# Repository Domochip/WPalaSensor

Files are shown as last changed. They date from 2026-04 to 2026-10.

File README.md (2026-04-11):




# WPalaSensor

This project aims to replace the Palazzetti (Fumis) room temperature sensor by an electronic simulator.  
It allows you to push home automation temperature to the stove.  
You can then keep native modulation that reduce power automatically when desired temperature is reached.  

Fumis Controller

## Compatibility

It appears that Fumis Controller is used by those brands for their stoves : 

* Palazzetti (All)
* Jotul
* TurboFonte
* Godin
* Fonte Flamme
* Invicta

If you have this controller in your stove, it's likely to be compatible.  
Fumis Controller

## Build your adapter

All files are inside `schematic` subfolder and has been designed with KiCad (free and open source)

### Schematic

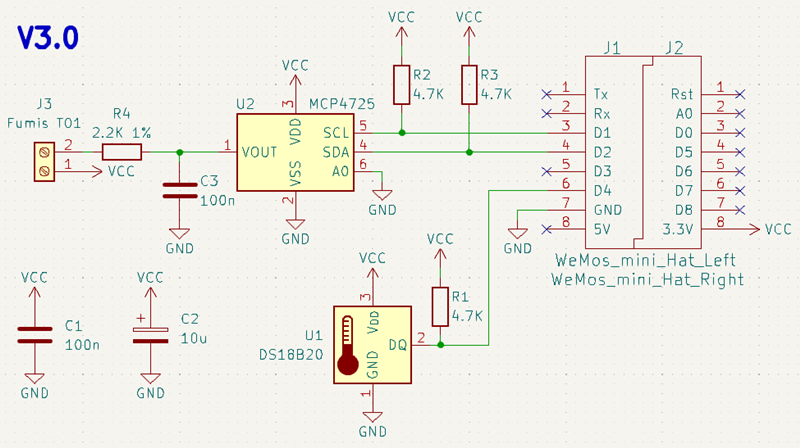
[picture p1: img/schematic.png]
WPalaSensor schematic


### PCB

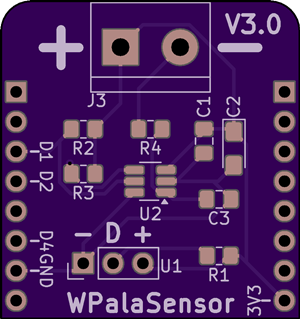
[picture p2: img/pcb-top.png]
WPalaSensor PCB
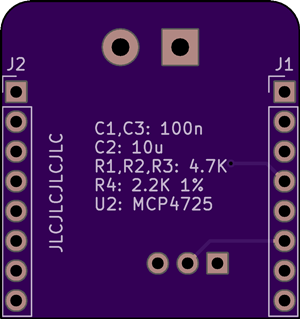
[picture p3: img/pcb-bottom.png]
WPalaSensor PCB2


*We produced a small batch of this adapter for test/debugging and our personal use.
If you are interested, please PM.*

### Print your box

Box project (Fusion 360 & STL) can be found into `box` folder

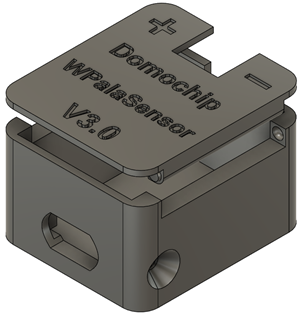
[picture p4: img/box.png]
WPalaSensor box


### Code/Compile/Flash

Source code can be compiled using VisualStudioCode/Platformio and flashed onto a D1 Mini  
Or  
Download latest release in Release section

### Connect

⚠️To connect WPalaSensor to your stove, you need to be very carefull about the polarity⚠️.  
Here is the polarity of two possible temperature sensors on Fumis motherboard:  
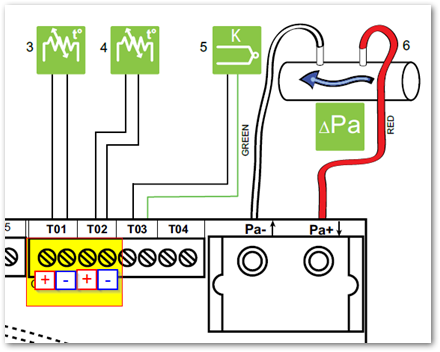
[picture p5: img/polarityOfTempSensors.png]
WPalaSensor polarity


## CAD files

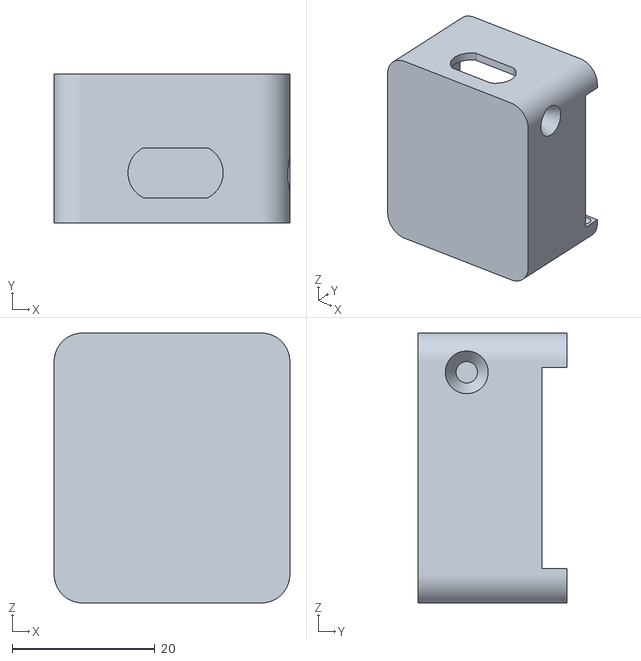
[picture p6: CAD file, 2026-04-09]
box/WPalaSensor Box.stl
33.0 x 20.8 x 37.8

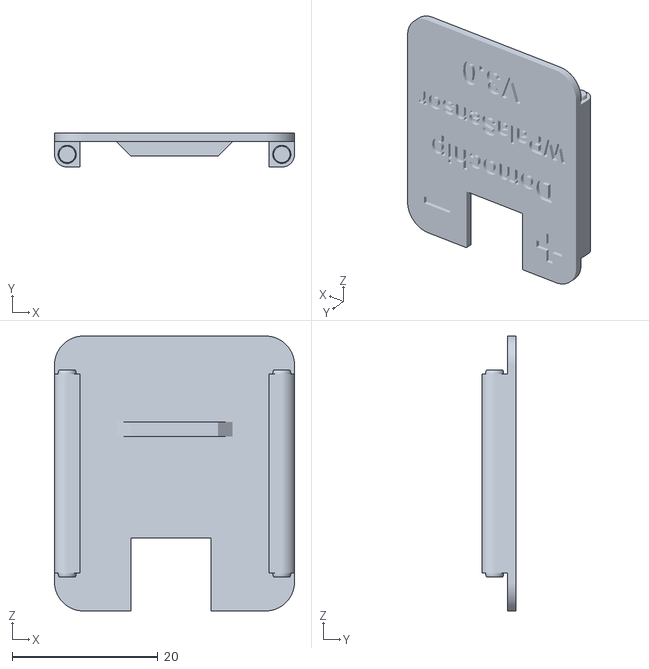
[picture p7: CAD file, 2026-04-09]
box/WPalaSensor Lid.stl
33.0 x 4.70 x 37.8

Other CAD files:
box/WPalaSensor v6.f3d

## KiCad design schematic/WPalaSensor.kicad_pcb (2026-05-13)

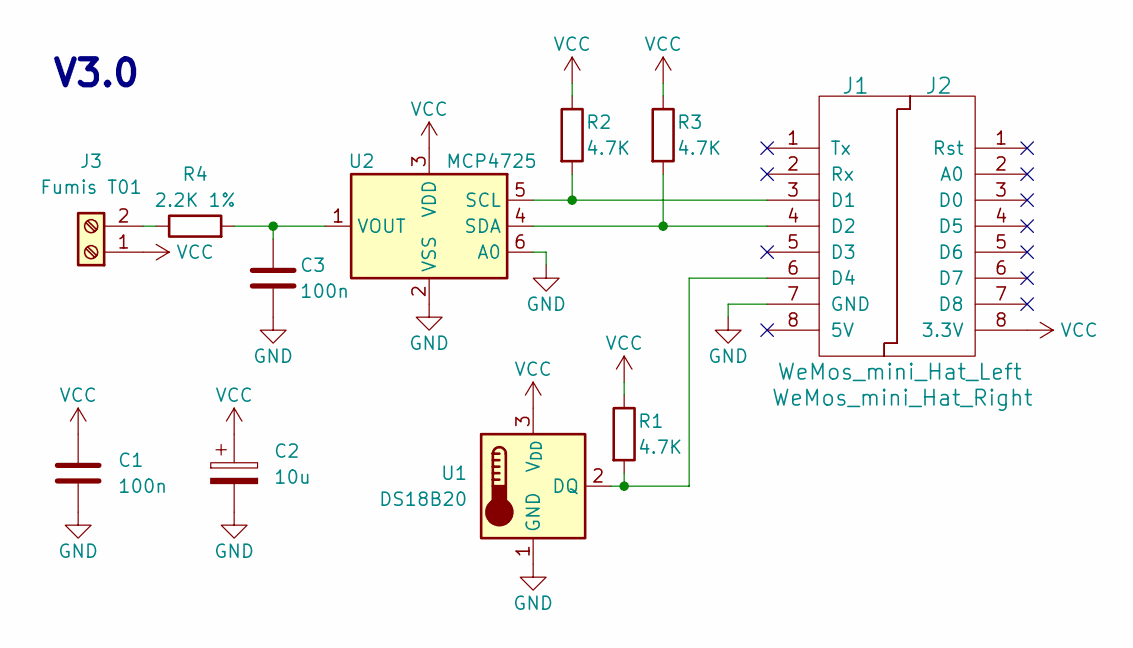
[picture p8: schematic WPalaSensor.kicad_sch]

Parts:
C1, C3: 100n; C_0805_2012Metric_Pad1.18x1.45mm_HandSolder; LCSC C49678
C2: 10u; CP_EIA-3216-18_Kemet-A_Pad1.58x1.35mm_HandSolder; LCSC C7171
J1: WeMos_mini_Hat_Left; WeMos_D1_mini_Hat_Left; LCSC C7509515
J2: WeMos_mini_Hat_Right; WeMos_D1_mini_Hat_Right; LCSC C7509515
J3: Fumis T01; TerminalBlock_bornier-2_P5.08mm; LCSC C474881
R1, R2, R3: 4.7K; R_0805_2012Metric_Pad1.20x1.40mm_HandSolder; LCSC C17673
R4: 2.2K 1%; R_0805_2012Metric_Pad1.20x1.40mm_HandSolder; LCSC C17520
U1: DS18B20; PinHeader_1x03_P2.54mm_Vertical
U2: MCP4725; SOT-23-6_Handsoldering; LCSC C144198

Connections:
GND: C1.2, C2.2, C3.2, J1.7 (GND), U1.1 (GND), U2.2 (VSS), U2.6 (A0)
unnamed: J1.3 (D1), R2.2, U2.5 (SCL)
unnamed: J1.4 (D2), R3.2, U2.4 (SDA)
unnamed: J1.6 (D4), R1.2, U1.2 (DQ)
unnamed: J3.2, R4.1
unnamed: C3.1, R4.2, U2.1 (VOUT)
VCC: C1.1, C2.1, J2.8 (3.3V), J3.1, R1.1, R2.1, R3.1, U1.3 (V_{DD}), U2.3 (VDD)

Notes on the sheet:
V3.0

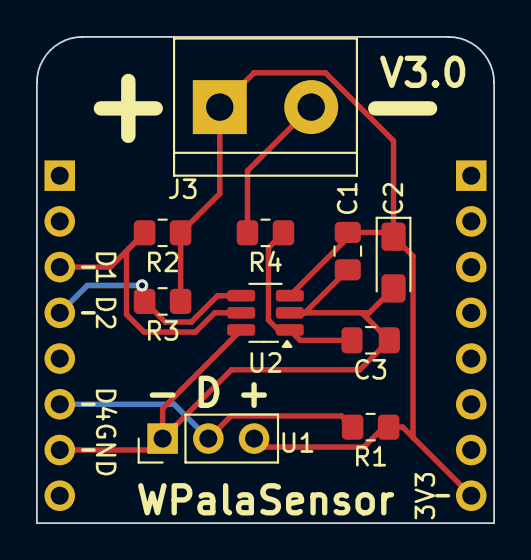
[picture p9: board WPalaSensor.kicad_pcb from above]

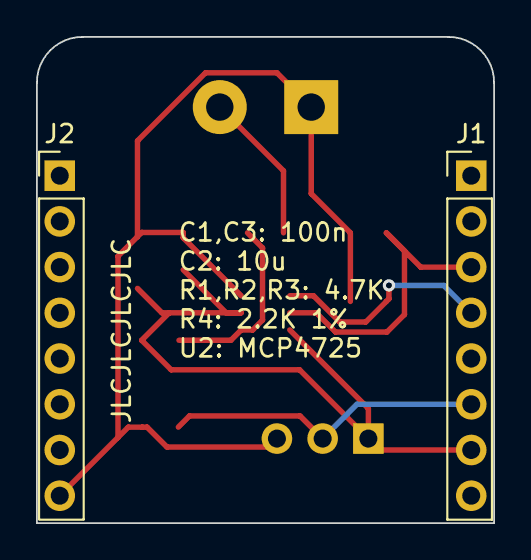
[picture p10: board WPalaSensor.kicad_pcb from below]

Board: 2 copper layers, 25.4 x 27.0 mm, 12 parts (2 on the bottom side), 7 nets.

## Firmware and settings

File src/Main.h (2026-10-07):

#ifndef Main_h
#define Main_h

#include <Arduino.h>

// Helper macros to convert a define to a string
#define STRINGIFY(x) #x
#define TOSTRING(x) STRINGIFY(x)

// ----- Should be modified for your application -----
#define CUSTOM_APP_MANUFACTURER "Domochip" // also used as Github user for OTA
#define CUSTOM_APP_MODEL "WPalaSensor"     // also used as Github repository for OTA
#define CUSTOM_APP_CLASS WPalaSensor
#define VERSION_NUMBER "4.3.7"

#define CUSTOM_APP_HEADER TOSTRING(CUSTOM_APP_CLASS.h) // calculated header file "{CUSTOM_APP_CLASS}.h"
#define DEFAULT_AP_SSID CUSTOM_APP_MODEL               // Default Access Point SSID "{CUSTOM_APP_MODEL}"
#define DEFAULT_AP_PSK "password"                      // Default Access Point Password

// Control SSEServer code (To be used by Application if Server-sent events are needed)
#define SSE_SERVER_ENABLED 0
#define SSE_SERVER_MAX_CLIENTS 2
#define SSE_SERVER_KEEPALIVE 0

// Pin for 1Wire DS18B20 bus
#ifdef ESP8266
#define ONEWIRE_BUS_PIN D4
#else
#define ONEWIRE_BUS_PIN 16
#endif

// Enable developper mode
#define DEVELOPPER_MODE 0

// Log Serial Object
#define LOG_SERIAL Serial
// Choose Log Serial Speed
#define LOG_SERIAL_SPEED 115200

// Log Serial Macros
#ifdef LOG_SERIAL
#define LOG_SERIAL_PRINT(...) LOG_SERIAL.print(__VA_ARGS__)
#define LOG_SERIAL_PRINTLN(...) LOG_SERIAL.println(__VA_ARGS__)
#define LOG_SERIAL_PRINTF(...) LOG_SERIAL.printf(__VA_ARGS__)
#define LOG_SERIAL_PRINTF_P(...) LOG_SERIAL.printf_P(__VA_ARGS__)
#else
#define LOG_SERIAL_PRINT(...)
#define LOG_SERIAL_PRINTLN(...)
#define LOG_SERIAL_PRINTF(...)
#define LOG_SERIAL_PRINTF_P(...)
#endif

// Choose Pin used to boot in Rescue Mode
// #define RESCUE_BTN_PIN 16

// Status LED
// #define STATUS_LED_SETUP pinMode(XX, OUTPUT);pinMode(XX, OUTPUT);
// #define STATUS_LED_OFF digitalWrite(XX, HIGH);digitalWrite(XX, HIGH);
// #define STATUS_LED_ERROR digitalWrite(XX, HIGH);digitalWrite(XX, HIGH);
// #define STATUS_LED_WARNING digitalWrite(XX, HIGH);digitalWrite(XX, HIGH);
// #define STATUS_LED_GOOD digitalWrite(XX, HIGH);digitalWrite(XX, HIGH);

// construct Version text
#if DEVELOPPER_MODE
#define _DEV_SUFFIX "-DEV"
#else
#define _DEV_SUFFIX ""
#endif

#ifdef DEBUG
#define _DEBUG_SUFFIX "-DEBUG"
#else
#define _DEBUG_SUFFIX ""
#endif

#define VERSION VERSION_NUMBER _DEV_SUFFIX _DEBUG_SUFFIX

#endif

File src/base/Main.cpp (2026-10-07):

#ifdef ESP8266
#include <ESP8266WiFi.h>
#include <ESP8266WebServer.h>
using WebServer = ESP8266WebServer;
#else
#include <WiFi.h>
#include <WebServer.h>
#endif
#include <EEPROM.h>
#include <LittleFS.h>
#include <FS.h>

#include "Version.h"
#include "../Main.h"
#include "SystemState.h"
#include "Application.h"
#include "Core.h"
#include "WifiMan.h"

// include Custom Application header file
#include CUSTOM_APP_HEADER

// WebServer
WebServer server(80);

// Core App
Core core;

// WifiMan App
WifiMan wifiMan;

// Custom App
CUSTOM_APP_CLASS custom;

//-----------------------------------------------------------------------
// Setup function
//-----------------------------------------------------------------------
void setup()
{
#ifdef LOG_SERIAL
  LOG_SERIAL.begin(LOG_SERIAL_SPEED);
  LOG_SERIAL_PRINTLN();
  LOG_SERIAL_PRINTLN();
  LOG_SERIAL.flush();
#endif

#ifdef STATUS_LED_SETUP
  STATUS_LED_SETUP
#endif
#ifdef STATUS_LED_ERROR
  STATUS_LED_ERROR
#endif

  LOG_SERIAL_PRINTLN(F(CUSTOM_APP_MANUFACTURER " " CUSTOM_APP_MODEL " " VERSION));
  LOG_SERIAL_PRINTLN(F("---Booting---"));

#ifndef RESCUE_BUTTON_WAIT
#define RESCUE_BUTTON_WAIT 3
#endif

  bool skipExistingConfig = false;

  // look into EEPROM for Rescue mode flag
  EEPROM.begin(4);
  skipExistingConfig = EEPROM.read(0) != 0;
  if (skipExistingConfig)
    EEPROM.write(0, 0);
  EEPROM.end();

#ifdef RESCUE_BTN_PIN
  // if config already skipped, don't wait for rescue button
  if (!skipExistingConfig)
  {
    LOG_SERIAL_PRINTF_P(PSTR("Wait Rescue button for %d seconds\n"), RESCUE_BUTTON_WAIT);

    pinMode(RESCUE_BTN_PIN, (RESCUE_BTN_PIN != 16) ? INPUT_PULLUP : INPUT);
    for (int i = 0; i < 100 && skipExistingConfig == false; i++)
    {
      if (digitalRead(RESCUE_BTN_PIN) == LOW)
        skipExistingConfig = true;
      delay(RESCUE_BUTTON_WAIT * 10);
    }
  }
#endif

  if (skipExistingConfig)
  {
    LOG_SERIAL_PRINTLN(F("-> RESCUE MODE : Stored configuration won't be loaded."));
  }
  
#ifdef ESP8266
  if (!LittleFS.begin())
#else
  if (!LittleFS.begin(true))
#endif
  {
    LOG_SERIAL_PRINTLN(F("/!\\   File System Mount Failed   /!\\"));
    LOG_SERIAL_PRINTLN(F("/!\\ Configuration can't be saved /!\\"));
  }

#ifdef ESP8266
  // Init CrashSaver
  CrashSaver::init(LittleFS);
#endif

  // Init Core
  core.init(skipExistingConfig);

  // Init WiFi
  wifiMan.init(skipExistingConfig);

  // Init Custom Application
  custom.init(skipExistingConfig);

  LOG_SERIAL_PRINT(F("Start WebServer : "));

  core.initWebServer(server);
  wifiMan.initWebServer(server);
  custom.initWebServer(server);

  server.begin();

  LOG_SERIAL_PRINTLN(F("OK"));
  LOG_SERIAL_PRINTLN(F("---End of setup()---"));
}

//-----------------------------------------------------------------------
// Main Loop function
//-----------------------------------------------------------------------
void loop(void)
{

  // Handle WebServer
  server.handleClient();

  if (!SystemState::pauseCustomApp && !SystemState::shouldReboot)
    custom.run();

  wifiMan.run();

  // required to maintain WiFi and send tcp packets (particularly for mesh wifi)
#ifdef ESP8266
  delay(10);
#endif

  if (SystemState::shouldReboot)
  {
#ifdef LOG_SERIAL
    LOG_SERIAL_PRINTLN(F("Rebooting..."));
    delay(100);
    LOG_SERIAL.end();
#endif
    ESP.restart();
  }
}

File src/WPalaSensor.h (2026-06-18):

#ifndef WPalaSensor_h
#define WPalaSensor_h

#include "Main.h"
#include "base/WifiMan.h"
#include "base/MQTTMan.h"
#include "base/Application.h"

#ifdef ESP8266
#include <ESP8266HTTPClient.h>
#else
#include <HTTPClient.h>
#endif
#include <SPI.h>
#include <math.h>
#include <Ticker.h>
#include "SingleDS18B20.h"
#include <MCP4725.h>

class WPalaSensor : public Application
{
private:
  // -------------------- HomeAutomation Classes --------------------

  enum class HaHttpType : uint8_t
  {
    Jeedom = 0,
    Fibaro = 1,
    HomeAssistant = 2
  };

  enum class HaProtocol : uint8_t
  {
    Disabled = 0,
    Http = 1,
    Mqtt = 2
  };

  enum class CBoxProtocol : uint8_t
  {
    Disabled = 0,
    Http = 1,
    Mqtt = 2
  };

  struct HTTP
  {
    HaHttpType type;
    char hostname[64 + 1];
    bool tls;
    int temperatureId;
    char secret[183 + 1]; // store Home Assistant long lived access token or Jeedom API key or Fibaro password

    struct
    {
      char username[64 + 1];
    } fibaro;

    struct
    {
      char entityId[64 + 1];
    } homeassistant;

    uint32_t cboxIp;
  };

  struct MQTT
  {
    char hostname[64 + 1];
    uint16_t port;
    char username[32 + 1];
    char password[64 + 1];
    char baseTopic[64 + 1];
    bool hassDiscoveryEnabled;
    char hassDiscoveryPrefix[32 + 1];

    char temperatureTopic[64 + 1];

    char cboxT1Topic[32 + 1];
  };

  struct HomeAutomation
  {
    HaProtocol protocol;
    uint16_t temperatureTimeout;
    CBoxProtocol cboxProtocol;
    uint16_t cboxTemperatureTimeout;

    HTTP http;
    MQTT mqtt;
  };

  // --------------------

  uint8_t _refreshPeriod;
  // Steinhart-Hart coefficient A
  double _shA;
  // Steinhart-Hart coefficient B
  double _shB;
  // Steinhart-Hart coefficient C
  double _shC;
  HomeAutomation _ha;

  // Run variables

  SingleDS18B20 _ds18b20;
  MCP4725 _dac;

  bool _needRefresh = false;
  Ticker _refreshTicker;
  uint8_t _skipTick = 0;
  bool _needPublishHassDiscovery = false;
  bool _needPublishUpdate = false;
  Ticker _publishUpdateTicker;

  // Used in refresh method for logic and calculation

  // to avoid delta calculation on first call (then 20° is applied at first call and then delta is calculated at least during 2nd call)
  bool _firstRefreshTick = true;

  float _haTemperature = 20.0;
  unsigned long _haTemperatureMillis = 0;
  int _haRequestResult = 0;
  float _owTemperature = 0.0;
  bool _haTemperatureUsed = false;
  float _lastTemperatureUsed = 20.0;

  float _stoveTemperature = 20.0;
  unsigned long _stoveTemperatureMillis = 0;
  int _stoveRequestResult = 0;

  float _stoveDelta = 0.0;
  float _pushedTemperature = 20.0;

  WiFiClient _wifiClient; // used by _mqttMan
  MQTTMan _mqttMan;

  void setDac(float temperature, bool EEPROM = false);
  void setDac(int resistance, bool EEPROM = false);
  void fetchHaTemperatureHttp();
  void fetchCBoxTemperatureHttp();
  void refresh();
  void mqttConnectedCallback(MQTTMan *mqttMan, bool firstConnection);
  void mqttCallback(char *topic, uint8_t *payload, unsigned int length);
  bool mqttPublishHassDiscovery();
  void mqttPublishHassDiscovery(HassDiscoveryCtx &ctx);

  void setConfigDefaultValues();
  bool parseConfigJSON(JsonVariant json, bool fromWebPage = false);
  void validateConfig() override;
  void fillConfigJSON(JsonVariant json, bool forSaveFile = false);
  void fillStatusJSON(JsonVariant json);
  bool appInit(bool reInit = false);
  void appInitWebServer(WebServer &server);
  void appRun();

public:
  WPalaSensor();
};

#endif

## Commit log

2024-10-25 Factorize calibrator buttons code
2024-11-01 Fix default AP password
    [Main.h]
2024-12-01 Fix local temp sensor not working (_tempSensorFound always false)
2026-04-06 Update schematic version
    [WirelessPalaSensor.kicad_pcb, WirelessPalaSensor.kicad_sch]
2026-04-07 New hw dac based (#6)
    * Update schematic and libraries
    * Remove DigiPot lib
    * Create Mcp4725 class
    * Add version to schematic
    * Add R4
    * Start using a readily available library for MCP4725
    * Replace setDualDigiPot functions by setDAC functions
    * Adapt appInitWebServer function for DAC
    * Continue replacement of DigiPots to DAC
    * Remove Digipot variables
    * Add EEPROM param
    * Init DAC
    * Set default value of 20°C in EEPROM
    * Update webpages
    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
    [WPalaSensor Box.stl, WPalaSensor Lid.stl, WPalaSensor v12.f3d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]
2026-04-07 Switch to PubSubClient3 lib which is maintained
2026-04-09 box reworked
    [WPalaSensor Box.stl, WPalaSensor Lid.stl, WPalaSensor v12.f3d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]
2026-05-13 Update to Kicad 10
    [WPalaSensor.kicad_pcb, WPalaSensor.kicad_sch]
2026-05-17 use a buffer to render temperature strings to avoid heap fragmentation
2026-05-27 Clean up getHTMLContent and getHTMLContentSize switch cases
2026-06-06 Replace byte type by uint8_t for enum class
    [WPalaSensor.h]
2026-06-06 finishing byte replacement by uint8_t
    [WPalaSensor.h]
2026-06-17 Add Temperature Fallback binary sensor entity to MQTT discovery
2026-06-17 Return NAN for temperature read failures instead of a placeholder value
2026-06-18 Clarify sensor detection and avoid confusion
2026-06-18 Refactor temperature rounding to use roundTenth function for consistency
2026-11-03 Add JSON payload support for MQTT temperatures (#8)
    * Add JSON payload indicator and json key variables
    * Add temperature json payload config init, save and load
    * Add JSON payload option and temperature key input to config page
    * Reduce temperature key buffer size
    * Implement JSON payloads handling for MQTT temperature
    * Factorize MQTT temperature parsing for HA and Stove
2026-11-03 in Status page, group temperatures and ages together
2026-11-03 Rename HA temperature fields in JSON and HTML for consistency
2026-11-03 Add age increment functionality for temperature fields in status page
2026-11-03 Add functions to fill JSON with last temperatures and their ages for HA and CBox
2026-11-03 Add SSE broadcasting for updated HA and CBox temperatures
2026-11-03 Add SSE broadcasting for HTTP response codes in temperature fetch functions
2026-11-03 Fix temperature key input to 16 characters
2026-11-04 Refactor JSON handling: consolidate temperature broadcasting into fillStatusJSON and remove unused functions
2026-11-04 Add pushed temperature age tracking and update status display
2026-11-08 Replace publishupdate ticker by a millis logic
2026-11-08 Replace refresh ticker by a millis logic
2026-11-10 Enhance addClickListener function to include error handling and update result selectors for calibration inputs
2026-11-10 Add error handling to calibration calculation and display results
2026-11-10 Add setDacValue function and improve resistance handling in setDac
2026-11-10 Add timeout for temperature conversion to prevent indefinite blocking
2026-11-10 Limit stove temperature delta to ±5.0°C in refresh method
2026-11-10 Refactor calibration button to use button element and improve event handling
2026-11-10 Reset calibration pause on app initialization to ensure new configuration applies
